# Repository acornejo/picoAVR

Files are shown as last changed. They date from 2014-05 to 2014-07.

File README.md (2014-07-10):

# [PicoAVR](http://acornejo.github.io/picoAVR)

[PicoAVR](http://acornejo.github.io/picoAVR) is an open source AVR
development board which aims to a minimalistic but fully functional
alternative to Arduino.
The PicoAVR board measures less than 1 square inch, and for less than 10$ you can buy all the components to build your own.

Blinky Blinky on PicoAVR

The PicoAVR can be powered and programmed through a standard MicroUSB
connector, the same connector used by android phones and tablets.
PicoAVR uses the [V-USB](http://www.obdev.at/products/vusb/index.html)
software implementation of the USB stack, and when connected to your
computer can easily be programmed to emulate a keyboard,
mouse or any other HID device.

The PicoAVR board is similar in capabilities to the [Arduino
UNO](http://arduino.cc/en/Main/ArduinoBoardUno), [Arduino
Micro](http://arduino.cc/en/Main/arduinoBoardMicro) or the [Arduino
Leonardo](http://arduino.cc/en/Main/arduinoBoardLeonardo), but by using
an atmega328p and V-USB instead of an FTDI chip or an atmega328u4 the
number of components and the cost of the PicoAVR is significantly
reduced.

Since PicoAVR uses the same
[protocol](http://www.obdev.at/products/vusb/usbasploader.html) as the
[usbasp](www.fischl.de/usbasp/) for programming, it is supported by
the latest versions of avrdude. As a result both 
Atmel Studio 6 or the Arduino Software can be used as complete
development environments for the PicoAVR. However, you are not
constrained to these, and you can easily develop for the PicoAVR using
avr-gcc, avrdude and the editor of your choice.

In its default configuration the PicoAVR runs at 12 Mhz and operates at
3.3 V, which makes it easy to interface to the newer 3.3 V devices without
requiring a level shifter.

## PicoAVR may be interesting to you if...

* You are already developing hardware projects using an Arduino, but you
would prefer to build your own hardware.
* You want to get started with AVR microcontrollers, but don't want to
spend 25$ on an Arduino UNO or an Arduino Micro.
* You want an AVR development board which has a standard 6-pin ICSP
connector and can be used as an ICSP programmer for other
microcontrollers.
* You want to create a board of your own using an AVR microcontroller
and you are looking for a simple reference design.

## Build Your Own

You can buy the components to build your own for less than 10$ per board.

Moreover, keep in mind that due to economies of scale, building 100 or
1000 PicoAVR's is significantly cheaper per unit than building a single
board.

The only equipment required to build your own PicoAVR is a soldering
iron and an ICSP programmer to flash the bootloader (more on that below).

### BOM

|Part  | Description | Package | DigiKey Part # | Price ($) |
|---|---|---|---|---|
|C1,C2 | 4.7uF Capacitor | 402 | 1276-1056-1-ND | 0.23 x 2  |
|C3,C4 | 22pF  Capacitor | 402 | 1276-1681-1-ND | 0.1 x 2 |
|C5,C6 | 0.1uF Capacitor | 402 | 1276-1443-1-ND | 0.1 x 2 |
|R1,R2 | 68 Ohm Resistor | 402 | RMCF0402JT68R0CT-ND  | 0.02 x 2  |
|R3 | 1.5k Ohm Resistor | 402 | RMCF0402JT1K50CT-ND  | 0.02 x 1  |
|R4 | 10k Ohm Resistor | 402 | RMCF0402JT10K0CT-ND  | 0.02 x 1  |
|R5 | 220 Ohm Resistor | 402 | RMCF0402JT220RCT-ND  | 0.02 x 1  |
|Q1 | 12 Mhz Crystal | 3.2 x 2.5mm  | 887-2355-1-ND | 0.71 x 1  |
|U1 | Atmega328p | TQFP-32 | ATMEGA328P-AU-ND | 3.61 x 1  |
|IC1 | MCP1700 Voltage Regulator | SOT23 | MCP1700T3302ETTCT-ND | 0.44 x 1  |
|X1 | MicroUSB Connector | USB-MICRO | 609-4613-1-ND | 0.46 x 1  |
|SW1 | Tactile Switch | 3mm x 4mm | CKN10502CT-ND | 0.28 x 1  |

The total comes to less than 6.5$ per board. Digikey offers educational and
bulk discounts.

### PCB

You can get 3 PCB's from [oshpark.com](https://oshpark.com/shared_projects/4zQfKzvO) for only 4.95$
including shipping. That is less than 2$ per PicoAVR board! Click [here](https://oshpark.com/shared_projects/4zQfKzvO) to order your own. 

The eagle board files are available in the
[repository](https://github.com/acornejo/picoAVR/tree/master/hardware).

Below is a rendering of the top and bottom of the PCB.

TopBoard Top View PCB
BottomBoard Bottom View PCB

### Flashing the Bootloader
To get the PicoAVR usbasp-based bootloader flashed into the AVR chip you will
need either: a dedicated [ICSP
programmer](http://store.atmel.com/PartDetail.aspx?q=p:10500054#tc:description),
an [Arduino](http://arduino.cc/en/Tutorial/ArduinoISP) and jumper
cables, or an already functioning PicoAVR.

The PicoAVR provides a standard 6-pin ICSP connector that can be used to
either flash the bootloader into the board (by closing the self-program
jumper), or to act as an ICSP programmer to reprogram any other
AVR board (including another PicoAVR or an Arduino) using a standard
6-pin ICSP connector.

## License

[MIT License](http://opensource.org/licenses/MIT)

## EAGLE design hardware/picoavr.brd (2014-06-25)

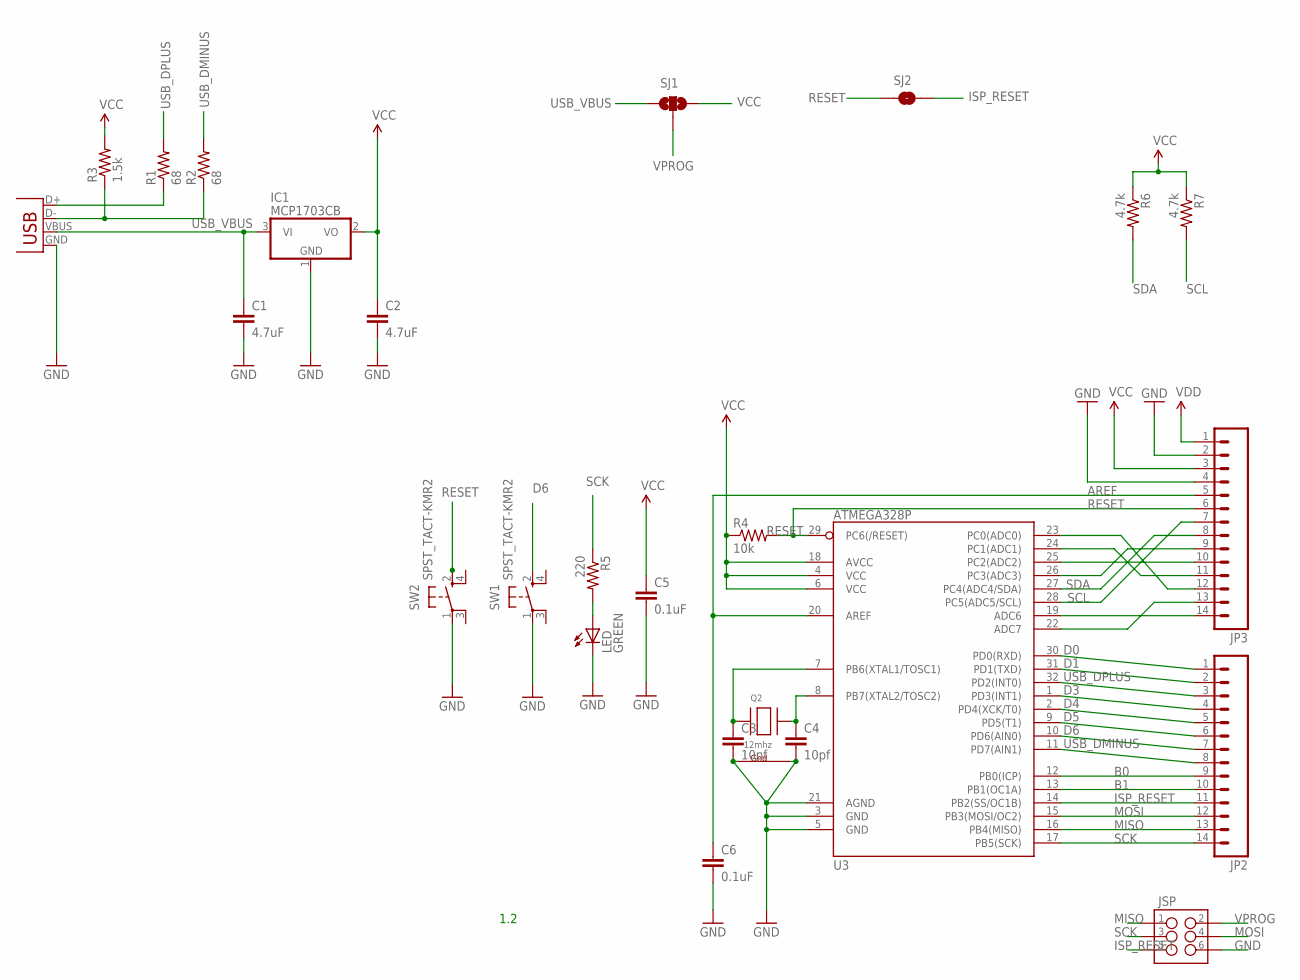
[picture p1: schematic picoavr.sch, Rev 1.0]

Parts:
C1, C2: 4.7uF; 0402-CAP
C3, C4: 10pf; 0402-CAP
C5, C6: 0.1uF; 0402-CAP
IC1: MCP1703CB; SOT23
JP2, JP3: M14LOCK; 1X14_LOCK
JSP: ICSP; 2X3-NS
LED: GREEN; LED-0603
Q2: 12mhz; NX3225
R1, R2: 68; R0402
R3: 1.5k; R0402
R4: 10k; R0402
R5: 220; 0402-RES
R6, R7: 4.7k; 0402-RES
SJ1: SJ1; SJ_3
SJ2: SOLDERJUMPERNO; SJ_2S-NO
SW1, SW2: SPST_TACT-KMR2; KMR2
U3: ATMEGA328P; TQFP32-08
X1: Micro USB; USB-MICROB

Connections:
A0: JP3.12, U3.23 (PC0(ADC0))
A1: JP3.11, U3.24 (PC1(ADC1))
A2: JP3.10, U3.25 (PC2(ADC2))
A3: JP3.9, U3.26 (PC3(ADC3))
A6: JP3.14, U3.19 (ADC6)
A7: JP3.13, U3.22 (ADC7)
AREF: C6.1, JP3.5, U3.20 (AREF)
B0: JP2.9, U3.12 (PB0(ICP))
B1: JP2.10, U3.13 (PB1(OC1A))
D0: JP2.1, U3.30 (PD0(RXD))
D1: JP2.2, U3.31 (PD1(TXD))
D3: JP2.4, U3.1 (PD3(INT1))
D4: JP2.5, U3.2 (PD4(XCK/T0))
D5: JP2.6, U3.9 (PD5(T1))
D6: JP2.7, SW1.2 (S), U3.10 (PD6(AIN0))
GND: C1.2, C2.2, C3.2, C4.2, C5.2, C6.2, IC1.1 (GND), JP3.2, JP3.4, JSP.6, LED.C, Q2.2 (G2), Q2.4 (G1), SW1.1, SW2.1, U3.3 (GND), U3.5 (GND), U3.21 (AGND), X1.GND
ISP_RESET: JP2.11, JSP.5, SJ2.2, U3.14 (PB2(SS/OC1B))
MISO: JP2.13, JSP.1, U3.16 (PB4(MISO))
MOSI: JP2.12, JSP.4, U3.15 (PB3(MOSI/OC2))
unnamed: R1.1, X1.D+
unnamed: R2.1, R3.1, X1.D-
unnamed: C4.1, Q2.3 (X2), U3.8 (PB7(XTAL2/TOSC2))
unnamed: C3.1, Q2.1 (X1), U3.7 (PB6(XTAL1/TOSC1))
unnamed: LED.A, R5.2
RESET: JP3.6, R4.2, SJ2.1, SW2.2 (S), U3.29 (PC6(/RESET))
SCK: JP2.14, JSP.3, R5.1, U3.17 (PB5(SCK))
SCL: JP3.7, R7.2, U3.28 (PC5(ADC5/SCL))
SDA: JP3.8, R6.2, U3.27 (PC4(ADC4/SDA))
USB_DMINUS: JP2.8, R2.2, U3.11 (PD7(AIN1))
USB_DPLUS: JP2.3, R1.2, U3.32 (PD2(INT0))
USB_VBUS: C1.1, IC1.3 (VI), JP3.1, SJ1.1, X1.VBUS
VCC: C2.1, C5.1, IC1.2 (VO), JP3.3, R3.2, R4.1, R6.1, R7.1, SJ1.3, U3.4 (VCC), U3.6 (VCC), U3.18 (AVCC)
VPROG: JSP.2, SJ1.2

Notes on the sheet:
1.2

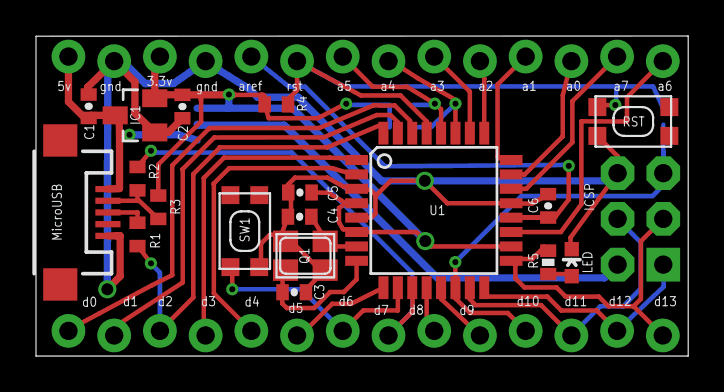
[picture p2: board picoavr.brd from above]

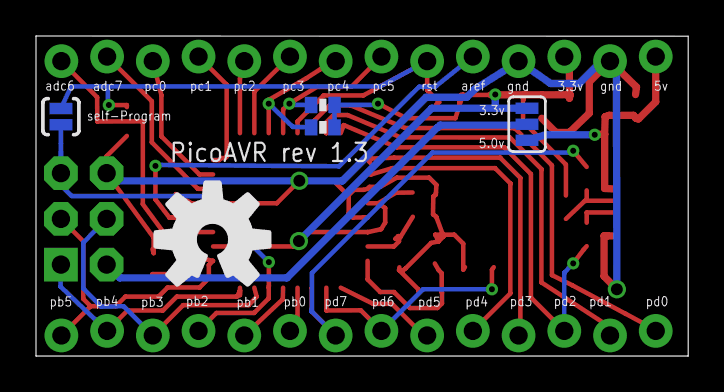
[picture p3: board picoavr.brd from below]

Board: 2 copper layers, 36.2 x 17.8 mm, 25 parts (4 on the bottom side), 33 nets.

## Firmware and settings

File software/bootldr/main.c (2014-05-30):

/* Name: main.c
 * Project: USBaspLoader
 * Author: Christian Starkjohann
 * Author: Stephan Baerwolf
 * Creation Date: 2007-12-08
 * Modification Date: 2013-03-31
 * Tabsize: 4
 * Copyright: (c) 2007 by OBJECTIVE DEVELOPMENT Software GmbH
 * License: GNU GPL v2 (see License.txt)
 */

#include "spminterface.h"  /* must be included as first! */

#include <avr/io.h>
#include <avr/interrupt.h>
#include <avr/pgmspace.h>
#include <avr/wdt.h>
#include <avr/boot.h>
#include <avr/eeprom.h>
#include <util/delay.h>
#include <avr/boot.h>

#include <string.h>

#ifndef SPMEN
#define SPMEN SELFPRGEN
#endif



#include "bootloaderconfig.h"
#include "../usbdrv/usbdrv.h"

#ifndef BOOTLOADER_ADDRESS
  #error need to know the bootloaders flash address!
#endif
#define BOOTLOADER_PAGEADDR	(BOOTLOADER_ADDRESS - (BOOTLOADER_ADDRESS % SPM_PAGESIZE))

/* ------------------------------------------------------------------------ */

/* Request constants used by USBasp */
#define USBASP_FUNC_CONNECT         1
#define USBASP_FUNC_DISCONNECT      2
#define USBASP_FUNC_TRANSMIT        3
#define USBASP_FUNC_READFLASH       4
#define USBASP_FUNC_ENABLEPROG      5
#define USBASP_FUNC_WRITEFLASH      6
#define USBASP_FUNC_READEEPROM      7
#define USBASP_FUNC_WRITEEEPROM     8
#define USBASP_FUNC_SETLONGADDRESS  9

// additional USBasp Commands
#define USBASP_FUNC_SETISPSCK	     10
#define USBASP_FUNC_TPI_CONNECT      11
#define USBASP_FUNC_TPI_DISCONNECT   12
#define USBASP_FUNC_TPI_RAWREAD      13
#define USBASP_FUNC_TPI_RAWWRITE     14
#define USBASP_FUNC_TPI_READBLOCK    15
#define USBASP_FUNC_TPI_WRITEBLOCK   16
#define USBASP_FUNC_GETCAPABILITIES 127
/* ------------------------------------------------------------------------ */

#ifndef ulong
#   define ulong    unsigned long
#endif
#ifndef uint
#   define uint     unsigned int
#endif

/* device compatibility: */
#ifndef GICR    /* ATMega*8 don't have GICR, use MCUCR instead */
#   define GICR     MCUCR
#endif

/* ------------------------------------------------------------------------ */

#if (FLASHEND) > 0xffff /* we need long addressing */
#   define CURRENT_ADDRESS  currentAddress.l
#   define addr_t           ulong
#else
#   define CURRENT_ADDRESS  currentAddress.w[0]
#   define addr_t           uint
#endif

typedef union longConverter{
    addr_t  l;
    uint    w[sizeof(addr_t)/2];
    uchar   b[sizeof(addr_t)];
}longConverter_t;


#if (BOOTLOADER_CAN_EXIT)
#	if (BOOTLOADER_LOOPCYCLES_TIMEOUT)
#		if (BOOTLOADER_LOOPCYCLES_TIMEOUT < 256)
#			if ((HAVE_UNPRECISEWAIT))
volatile register uint8_t timeout_remaining __asm__("r2");
#			else
static volatile uint8_t timeout_remaining;
#			endif
#		else
static volatile uint16_t timeout_remaining;
#		endif
#	endif

#	define stayinloader_initialValue 0xfe
#	if ((HAVE_UNPRECISEWAIT))
/* here we have to assume we need to optimize for every byte */
volatile register uint8_t stayinloader __asm__("r17");
#	else
static volatile uint8_t stayinloader;
#	endif
#endif

static longConverter_t  	currentAddress; /* in bytes */
static uchar            	bytesRemaining;
static uchar            	isLastPage;
#if HAVE_EEPROM_PAGED_ACCESS
static uchar            	currentRequest;
#else
static const uchar      	currentRequest = 0;
#endif

static const uchar  signatureBytes[4] = {
#ifdef SIGNATURE_BYTES
    SIGNATURE_BYTES
#elif defined (__AVR_ATmega8535__)
    0x1e, 0x93, 0x08, 0
#elif defined (__AVR_ATmega8__) || defined (__AVR_ATmega8A__) || defined (__AVR_ATmega8HVA__)
    0x1e, 0x93, 0x07, 0
#elif defined (__AVR_ATmega16__)
    0x1e, 0x94, 0x03, 0
#elif defined (__AVR_ATmega32__)
    0x1e, 0x95, 0x02, 0
#elif defined (__AVR_ATmega48__) || defined (__AVR_ATmega48A__) || defined (__AVR_ATmega48P__)
    #error ATmega48 does not support bootloaders!
    0x1e, 0x92, 0x05, 0
#elif defined (__AVR_ATmega48PA__)
    #error ATmega48 does not support bootloaders!
    0x1e, 0x92, 0x0A, 0
#elif defined (__AVR_ATmega88__) || defined (__AVR_ATmega88A__) || defined (__AVR_ATmega88P__)
    0x1e, 0x93, 0x0a, 0
#elif defined (__AVR_ATmega88PA__)
    0x1e, 0x93, 0x0F, 0
#elif defined (__AVR_ATmega162__)
    0x1e, 0x94, 0x04, 0
#elif defined (__AVR_ATmega164A__)
    0x1e, 0x94, 0x0f, 0
#elif defined (__AVR_ATmega164P__) || defined (__AVR_ATmega164PA__)
    0x1e, 0x94, 0x0a, 0
#elif defined (__AVR_ATmega168__) || defined (__AVR_ATmega168A__) || defined (__AVR_ATmega168P__)
    0x1e, 0x94, 0x06, 0
#elif defined (__AVR_ATmega168PA__)
    0x1e, 0x94, 0x0B, 0
#elif defined (__AVR_ATmega324A__)
    0x1e, 0x95, 0x15, 0
#elif defined (__AVR_ATmega324P__)
    0x1e, 0x95, 0x08, 0
#elif defined (__AVR_ATmega324PA__)
    0x1e, 0x95, 0x11, 0
#elif defined (__AVR_ATmega328__)
    0x1e, 0x95, 0x14, 0
#elif defined (__AVR_ATmega328P__)
    0x1e, 0x95, 0x0f, 0
#elif defined (__AVR_ATmega640__)
    0x1e, 0x96, 0x08, 0
#elif defined (__AVR_ATmega644__) || defined (__AVR_ATmega644A__)
    0x1e, 0x96, 0x09, 0
#elif defined (__AVR_ATmega644P__) || defined (__AVR_ATmega644PA__)
    0x1e, 0x96, 0x0a, 0
#elif defined (__AVR_ATmega128__)
    0x1e, 0x97, 0x02, 0
#elif defined (__AVR_ATmega1280__)
    0x1e, 0x97, 0x03, 0
#elif defined (__AVR_ATmega1281__)
    0x1e, 0x97, 0x04, 0
#elif defined (__AVR_ATmega1284__)
    0x1e, 0x97, 0x06, 0
#elif defined (__AVR_ATmega1284P__)
    0x1e, 0x97, 0x05, 0
#elif defined (__AVR_ATmega2560__)
    0x1e, 0x98, 0x01, 0
#elif defined (__AVR_ATmega2561__)
    0x1e, 0x98, 0x02, 0
#else
#   if (defined(SIGNATURE_0) && defined(SIGNATURE_1) && defined(SIGNATURE_2))
#     warning "Device signature is not known - using AVR Libc suggestion..."
    SIGNATURE_0, SIGNATURE_1, SIGNATURE_2, 0
#   else
#     error "Device signature is not known, please edit main.c!"
#   endif
#endif
};

/* ------------------------------------------------------------------------ */

#if (HAVE_BOOTLOADERENTRY_FROMSOFTWARE)
void __attribute__ ((section(".init3"),naked,used,no_instrument_function)) __BOOTLOADERENTRY_FROMSOFTWARE__bootup_investigate_RAMEND(void);
void __BOOTLOADERENTRY_FROMSOFTWARE__bootup_investigate_RAMEND(void) {
  asm volatile (
    "in		%[mcucsrval]	,	%[mcucsrio]\n\t"
    "ldi	r29		,	%[ramendhi]\n\t"
    "ldi	r28		,	%[ramendlo]\n\t"
#if (FLASHEND>131071)
    "ld		%[result]	,	Y+\n\t"
    "cpi	%[result]	,	%[bootaddrhi]\n\t"
    "brne	__BOOTLOADERENTRY_FROMSOFTWARE__bootup_investigate_RAMEND_mismatch%=\n\t"
#endif
    "ld		%[result]	,	Y+\n\t"
    "cpi	%[result]	,	%[bootaddrme]\n\t"
    "ld		%[result]	,	Y+\n\t"
    "breq	__BOOTLOADERENTRY_FROMSOFTWARE__bootup_investigate_RAMEND_done%=\n\t"

    "__BOOTLOADERENTRY_FROMSOFTWARE__bootup_investigate_RAMEND_mismatch%=:\n\t"
    "ldi	%[result]	,	0xff\n\t"

    "__BOOTLOADERENTRY_FROMSOFTWARE__bootup_investigate_RAMEND_done%=:\n\t"
    : [result]		"=a" (__BOOTLOADERENTRY_FROMSOFTWARE__bootup_RAMEND_doesmatch),
      [mcucsrval]	"=a" (__BOOTLOADERENTRY_FROMSOFTWARE__bootup_MCUCSR)
    : [mcucsrio]	"I"  (_SFR_IO_ADDR(MCUCSR)),
#if (FLASHEND>131071)
      [ramendhi]	"M" (((RAMEND - 2) >> 8) & 0xff),
      [ramendlo]	"M" (((RAMEND - 2) >> 0) & 0xff),
      [bootaddrhi]	"M" (((__BOOTLOADERENTRY_FROMSOFTWARE__EXPECTEDADDRESS) >>16) & 0xff),
#else
      [ramendhi]	"M" (((RAMEND - 1) >> 8) & 0xff),
      [ramendlo]	"M" (((RAMEND - 1) >> 0) & 0xff),
#endif
      [bootaddrme]	"M" (((__BOOTLOADERENTRY_FROMSOFTWARE__EXPECTEDADDRESS) >> 8) & 0xff)
    
  );
}
#endif

#if (USE_BOOTUP_CLEARRAM)
/*
* Under normal circumstances, RESET will not clear contents of RAM.
* As always, if you want it done - do it yourself...
*/
void __attribute__ ((section(".init3"),naked,used,no_instrument_function)) __func_clearram(void);
void __func_clearram(void) {
  extern size_t __bss_end;
  asm volatile (
    "__clearram:\n\t"
#if (!(HAVE_BOOTLOADERENTRY_FROMSOFTWARE))
    "ldi r29, %[ramendhi]\n\t"
    "ldi r28, %[ramendlo]\n\t"
#endif
    "__clearramloop%=:\n\t"
    "st -Y , __zero_reg__\n\t"
    "cp r28, %A[bssend]\n\t"
    "cpc r29, %B[bssend]\n\t"
    "brne __clearramloop%=\n\t"
    :
    : [ramendhi] "M" (((RAMEND+1)>>8) & 0xff),
      [ramendlo] "M" (((RAMEND+1)>>0) & 0xff),
      [bssend] "r" (&__bss_end)
    : "memory"
      );
}
#endif

#if (!USE_EXCESSIVE_ASSEMBLER) || (!(defined (__AVR_ATmega8__) || defined (__AVR_ATmega8A__) || defined (__AVR_ATmega8HVA__)))
static void (*nullVector)(void) __attribute__((__noreturn__)) = 0x0000;
#endif

#if (USE_EXCESSIVE_ASSEMBLER) && (defined (__AVR_ATmega8__) || defined (__AVR_ATmega8A__) || defined (__AVR_ATmega8HVA__))
static void __attribute__((naked,__noreturn__)) leaveBootloader(void);
static void leaveBootloader(void) {
  asm  volatile  (
  "cli\n\t"
  "sbi		%[usbddr],	%[usbminus]\n\t"  
  "cbi		%[port],	%[bit]\n\t"
  "out		%[usbintrenab],	__zero_reg__\n\t"
  "out		%[usbintrcfg],	__zero_reg__\n\t"
  "ldi		r31,		%[ivce]\n\t"
  "out		%[mygicr],	r31\n\t"
  "out		%[mygicr],	__zero_reg__\n\t"  
  "rjmp		nullVector\n\t"
  :
  : [port]        "I" (_SFR_IO_ADDR(PIN_PORT(JUMPER_PORT))),
    [bit]         "I" (PIN(JUMPER_PORT, JUMPER_BIT)),
    [usbintrenab] "I" (_SFR_IO_ADDR(USB_INTR_ENABLE)),
    [usbintrcfg]  "I" (_SFR_IO_ADDR(USB_INTR_CFG)),
    [usbddr]      "I" (_SFR_IO_ADDR(USBDDR)),
    [usbminus]    "I" (USBMINUS),
    [mygicr]      "I" (_SFR_IO_ADDR(GICR)),	      
    [ivce]        "I" (1<<IVCE)
);
}
#else
static void __attribute__((__noreturn__)) leaveBootloader(void);
static void leaveBootloader(void) {
    cli();
    usbDeviceDisconnect();
    bootLoaderExit();
    USB_INTR_ENABLE = 0;
    USB_INTR_CFG = 0;       /* also reset config bits */
    GICR = (1 << IVCE);     /* enable change of interrupt vectors */
    GICR = (0 << IVSEL);    /* move interrupts to application flash section */

/*
 * There seems to be another funny compiler Bug.
 * When gcc is using "eicall" opcode it forgets to modify EIND.
 * On devices with large flash memory there are some target address bits
 * missing. In this case some zero bits...
 */
#if (defined(EIND) && ((FLASHEND)>131071))
  EIND=0;
#endif
/* We must go through a global function pointer variable instead of writing
 *  ((void (*)(void))0)();
 * because the compiler optimizes a constant 0 to "rcall 0" which is not
 * handled correctly by the assembler.
 */
    nullVector();
}
#endif

/* ------------------------------------------------------------------------ */


uchar usbFunctionSetup_USBASP_FUNC_TRANSMIT(usbRequest_t *rq) {
  uchar rval = 0;
  usbWord_t address;
  address.bytes[1] = rq->wValue.bytes[1];
  address.bytes[0] = rq->wIndex.bytes[0];

  if(rq->wValue.bytes[0] == 0x30){        /* read signature */
    rval = rq->wIndex.bytes[0] & 3;
    rval = signatureBytes[rval];
#if HAVE_READ_LOCK_FUSE
#if defined (__AVR_ATmega8535__) || 					\
    defined (__AVR_ATmega8__) || defined (__AVR_ATmega8A__) || 		\
    defined (__AVR_ATmega16__) || defined (__AVR_ATmega32__)
  }else if(rq->wValue.bytes[0] == 0x58 && rq->wValue.bytes[1] == 0x00){  /* read lock bits */
      rval = boot_lock_fuse_bits_get(GET_LOCK_BITS);
  }else if(rq->wValue.bytes[0] == 0x50 && rq->wValue.bytes[1] == 0x00){  /* read lfuse bits */
      rval = boot_lock_fuse_bits_get(GET_LOW_FUSE_BITS);
  }else if(rq->wValue.bytes[0] == 0x58 && rq->wValue.bytes[1] == 0x08){  /* read hfuse bits */
      rval = boot_lock_fuse_bits_get(GET_HIGH_FUSE_BITS);

#elif defined (__AVR_ATmega48__)   || defined (__AVR_ATmega48A__)   || defined (__AVR_ATmega48P__)   || defined (__AVR_ATmega48PA__)  ||  \
defined (__AVR_ATmega88__)   || defined (__AVR_ATmega88A__)   || defined (__AVR_ATmega88P__)   || defined (__AVR_ATmega88PA__)  ||  \
defined (__AVR_ATmega162__)  || 												      \
defined (__AVR_ATmega164A__) || defined (__AVR_ATmega164P__)  || 								      \
defined (__AVR_ATmega168__)  || defined (__AVR_ATmega168A__)  || defined (__AVR_ATmega168P__)  || defined (__AVR_ATmega168PA__) ||  \
defined (__AVR_ATmega324A__) || defined (__AVR_ATmega324P__)  ||								      \
defined (__AVR_ATmega328__)  || defined (__AVR_ATmega328P__)  ||								      \
defined (__AVR_ATmega640__)  ||													\
defined (__AVR_ATmega644__)  || defined (__AVR_ATmega644A__)  || defined (__AVR_ATmega644P__) || defined (__AVR_ATmega644PA__)  ||  \
defined (__AVR_ATmega128__)  ||													      \
defined (__AVR_ATmega1280__) ||													\
defined (__AVR_ATmega1281__) ||													\
defined (__AVR_ATmega1284__) || defined (__AVR_ATmega1284P__)  ||													\
defined (__AVR_ATmega2560__) ||													\
defined (__AVR_ATmega2561__)
  }else if(rq->wValue.bytes[0] == 0x58 && rq->wValue.bytes[1] == 0x00){  /* read lock bits */
      rval = boot_lock_fuse_bits_get(GET_LOCK_BITS);
  }else if(rq->wValue.bytes[0] == 0x50 && rq->wValue.bytes[1] == 0x00){  /* read lfuse bits */
      rval = boot_lock_fuse_bits_get(GET_LOW_FUSE_BITS);
  }else if(rq->wValue.bytes[0] == 0x58 && rq->wValue.bytes[1] == 0x08){  /* read hfuse bits */
      rval = boot_lock_fuse_bits_get(GET_HIGH_FUSE_BITS);
  }else if(rq->wValue.bytes[0] == 0x50 && rq->wValue.bytes[1] == 0x08){  /* read efuse bits */
      rval = boot_lock_fuse_bits_get(GET_EXTENDED_FUSE_BITS );
#else
  #warning "HAVE_READ_LOCK_FUSE is activated but MCU unknown -> will not support this feature"
#endif
#endif
#if HAVE_FLASH_BYTE_READACCESS
  }else if(rq->wValue.bytes[0] == 0x20){  /* read FLASH low  byte */
#if ((FLASHEND) > 65535)
      rval = pgm_read_byte_far((((addr_t)address.word)<<1)+0);
#else
      rval = pgm_read_byte((((addr_t)address.word)<<1)+0);
#endif
  }else if(rq->wValue.bytes[0] == 0x28){  /* read FLASH high byte */
#if ((FLASHEND) > 65535)
      rval = pgm_read_byte_far((((addr_t)address.word)<<1)+1);
#else
      rval = pgm_read_byte((((addr_t)address.word)<<1)+1);
#endif
#endif
#if HAVE_EEPROM_BYTE_ACCESS
  }else if(rq->wValue.bytes[0] == 0xa0){  /* read EEPROM byte */
      rval = eeprom_read_byte((void *)address.word);
  }else if(rq->wValue.bytes[0] == 0xc0){  /* write EEPROM byte */
      eeprom_write_byte((void *)address.word, rq->wIndex.bytes[1]);
#endif
#if HAVE_CHIP_ERASE
  }else if(rq->wValue.bytes[0] == 0xac && rq->wValue.bytes[1] == 0x80){  /* chip erase */
      addr_t addr;
#if HAVE_BLB11_SOFTW_LOCKBIT
      for(addr = 0; addr < (addr_t)(BOOTLOADER_PAGEADDR) ; addr += SPM_PAGESIZE) {
#else
      for(addr = 0; addr <= (addr_t)(FLASHEND) ; addr += SPM_PAGESIZE) {
#endif
#   ifndef NO_FLASH_WRITE
	  boot_spm_busy_wait();
	  cli();
	  boot_page_erase(addr);
	  sei();
#   endif
      }
#endif
#if ((HAVE_BOOTLOADER_HIDDENEXITCOMMAND) && (BOOTLOADER_CAN_EXIT))
#	if ((HAVE_BOOTLOADER_HIDDENEXITCOMMAND != 0xac) && \
	    (HAVE_BOOTLOADER_HIDDENEXITCOMMAND != 0x20) && (HAVE_BOOTLOADER_HIDDENEXITCOMMAND != 0x28) && \
	    (HAVE_BOOTLOADER_HIDDENEXITCOMMAND != 0x40) && (HAVE_BOOTLOADER_HIDDENEXITCOMMAND != 0x48) && \
	    (HAVE_BOOTLOADER_HIDDENEXITCOMMAND != 0x4c) && \
	    (HAVE_BOOTLOADER_HIDDENEXITCOMMAND != 0xa0) && \
	    (HAVE_BOOTLOADER_HIDDENEXITCOMMAND != 0xc0) && \
	    (HAVE_BOOTLOADER_HIDDENEXITCOMMAND != 0x58) && \
	    (HAVE_BOOTLOADER_HIDDENEXITCOMMAND != 0x5c) && \
	    (HAVE_BOOTLOADER_HIDDENEXITCOMMAND != 0x30) && \
	    (HAVE_BOOTLOADER_HIDDENEXITCOMMAND != 0xac) && \
	    (HAVE_BOOTLOADER_HIDDENEXITCOMMAND != 0x50) && (HAVE_BOOTLOADER_HIDDENEXITCOMMAND != 0x58) && \
	    (HAVE_BOOTLOADER_HIDDENEXITCOMMAND != 0x38))
  }else if(rq->wValue.bytes[0] == (HAVE_BOOTLOADER_HIDDENEXITCOMMAND)){  /* cause a bootLoaderExit at disconnect */
      stayinloader = 0xf1;  /* we need to be connected - so assume it */
#	endif
#endif
  }else{
      /* ignore all others, return default value == 0 */
  }
        
  return rval;
}


usbMsgLen_t usbFunctionSetup(uchar data[8])
{
usbRequest_t    *rq = (void *)data;
usbMsgLen_t     len = 0;
static uchar    replyBuffer[4];

    usbMsgPtr = (usbMsgPtr_t)replyBuffer;
    if(rq->bRequest == USBASP_FUNC_TRANSMIT){   /* emulate parts of ISP protocol */
        replyBuffer[3] = usbFunctionSetup_USBASP_FUNC_TRANSMIT(rq);
        len = (usbMsgLen_t)4;
    }else if((rq->bRequest == USBASP_FUNC_ENABLEPROG) || (rq->bRequest == USBASP_FUNC_SETISPSCK)){
        /* replyBuffer[0] = 0; is never touched and thus always 0 which means success */
        len = (usbMsgLen_t)1;
    }else if(rq->bRequest >= USBASP_FUNC_READFLASH && rq->bRequest <= USBASP_FUNC_SETLONGADDRESS){
        currentAddress.w[0] = rq->wValue.word;
        if(rq->bRequest == USBASP_FUNC_SETLONGADDRESS){
#if (FLASHEND) > 0xffff
            currentAddress.w[1] = rq->wIndex.word;
#endif
        }else{
            bytesRemaining = rq->wLength.bytes[0];
            /* if(rq->bRequest == USBASP_FUNC_WRITEFLASH) only evaluated during writeFlash anyway */
            isLastPage = rq->wIndex.bytes[1] & 0x02;
#if HAVE_EEPROM_PAGED_ACCESS
            currentRequest = rq->bRequest;
#endif
            len = USB_NO_MSG; /* hand over to usbFunctionRead() / usbFunctionWrite() */
        }

    }else if(rq->bRequest == USBASP_FUNC_DISCONNECT){

#if BOOTLOADER_CAN_EXIT
#	ifdef CONFIG_HAVE__BOOTLOADER_ABORTTIMEOUTONACT
      /* let the main loop know for ever that here was activity */
      stayinloader	   &= (0xfc);
#	else
      stayinloader	   &= (0xfe);
#	endif
#endif
    }else{
        /* ignore: others, but could be USBASP_FUNC_CONNECT */
#if BOOTLOADER_CAN_EXIT
	stayinloader	   |= (0x01);
#endif
    }
    return len;
}

#if (USE_EXCESSIVE_ASSEMBLER) && ((!HAVE_CHIP_ERASE) || (HAVE_ONDEMAND_PAGEERASE)) && (SPM_PAGESIZE <= 256) && (((BOOTLOADER_PAGEADDR>>0)&0xff) == 0)
uchar usbFunctionWrite(uchar *data, uchar len)
{
uchar   isLast;

    if(len > bytesRemaining)
        len = bytesRemaining;
    bytesRemaining -= len;
    isLast = bytesRemaining == 0;
    if(currentRequest >= USBASP_FUNC_READEEPROM){
        uchar i;
        for(i = 0; i < len; i++){
            eeprom_write_byte((void *)(currentAddress.w[0]++), *data++);
        }
    }else{
	asm  volatile  (
	  "sbrc		%[len], 0\n\t"
	  "inc		%[len]\n\t"
"usbFunctionWrite_flashloop:\n\t"
	  "subi		%[len], 2\n\t"
	  "brlo		usbFunctionWrite_finished\n\t"
	  
#if HAVE_BLB11_SOFTW_LOCKBIT
	  "cpi		r31, %[blsaddrhi]\n\t"			/* accelerated BLB11_SOFTW_LOCKBIT check */
	  "brsh		usbFunctionWrite_finished\n\t"
// 	  "brlo		usbFunctionWrite_addrunlock_ok\n\t"
// 	  "brne		usbFunctionWrite_finished\n\t"
// 	  "cpi		r30, %[blsaddrlo]\n\t"
// 	  "brlo		usbFunctionWrite_addrunlock_ok\n\t"
// 	  "rjmp		usbFunctionWrite_finished\n\t"
// "usbFunctionWrite_addrunlock_ok:\n\t"
#endif
	  "rcall	usbFunctionWrite_waitA\n\t"
	  "cli\n\t"						/* r0 or r1 may be __zero_reg__ and may become dangerous nonzero within interrupts */
	  "ld		r0,		X+\n\t"
	  "ld		r1,		X+\n\t"

	  "ldi		r18,		%[pagfillval]\n\t"
	  "rcall	usbFunctionWrite_saveflash\n\t"	/* page fill */

	  "mov		r18,		r30\n\t"
	  "subi		r18,		0xfe\n\t"		/* add with 2 */
	  "andi		r18,		%[pagemask]\n\t"
	  "breq		usbFunctionWrite_pageisfull\n\t"
	  "tst		%[islast]\n\t"
	  "breq		usbFunctionWrite_skippageisfull\n\t"
	  "tst		%[isLastPage]\n\t"
	  "breq		usbFunctionWrite_skippageisfull\n\t"
	  "cpi		%[len],		0\n\t"
	  "brne		usbFunctionWrite_skippageisfull\n\t"

"usbFunctionWrite_pageisfull:\n\t"				/* start writing the page */
	  "ldi		r18,		%[pageraseval]\n\t"
	  "rcall	usbFunctionWrite_saveflash\n\t"	/* page erase */
	  "rcall	usbFunctionWrite_waitA\n\t"

	  "ldi		r18,		%[pagwriteval]\n\t"
	  "rcall	usbFunctionWrite_saveflash\n\t"	/* page write */
	  "rcall	usbFunctionWrite_waitA\n\t"

	  "in		__tmp_reg__,	%[spmcr]\n\t"
	  "sbrs		__tmp_reg__,	%[rwwsbbit]\n\t"
	  "rjmp		usbFunctionWrite_skippageisfull\n\t"
	  "ldi		r18,		%[rwwenrval]\n\t"
	  "rcall	usbFunctionWrite_saveflash\n\t"	/* reenable rww*/
// 	  "rcall	usbFunctionWrite_waitA\n\t"


"usbFunctionWrite_skippageisfull:\n\t"	  
	  "adiw		r30,		0x2\n\t"
	  "rjmp		usbFunctionWrite_flashloop\n\t"

"usbFunctionWrite_saveflash:\n\t"
	  "cli\n\t"
	  "out		%[spmcr],	r18\n\t"
	  "spm\n\t"
	  "clr		__zero_reg__\n\t"			/* if r0 or r1 is __zero_reg__ it may have become inconsisten while page-fill */
	  "sei\n\t"
	  "ret\n\t"

"usbFunctionWrite_waitA:\n\t"
	  "in		__tmp_reg__,	%[spmcr]\n\t"
	  "sbrc		__tmp_reg__,	%[spmenbit]\n\t"
	  "rjmp		usbFunctionWrite_waitA\n\t"
	  "ret\n\t"

"usbFunctionWrite_finished:\n\t"
	  : [addr]	   "+z" (currentAddress.l)

	  : [spmenbit]    "I" (SPMEN),
	    [rwwsbbit]    "I" (RWWSB),
	    [spmcr]       "I" (_SFR_IO_ADDR(__SPM_REG)),
	    [pagfillval]  "M" ((1<<SPMEN)),
	    [pageraseval] "M" ((1<<PGERS) | (1<<SPMEN)),
	    [pagwriteval] "M" ((1<<PGWRT) | (1<<SPMEN)),
	    [rwwenrval]   "M" ((1<<RWWSRE) | (1<<SPMEN)),
	    [pagemask]    "M" (SPM_PAGESIZE-1),
#if HAVE_BLB11_SOFTW_LOCKBIT
	    [blsaddrhi]	   "M" ((uint8_t)((BOOTLOADER_PAGEADDR>>8)&0xff)),
// 	    [blsaddrlo]	   "M" ((uint8_t)((BOOTLOADER_PAGEADDR>>0)&0xff)),
#endif
	    [islast]      "r"  (isLast),
	    [isLastPage]  "r"  (isLastPage),
	    [len]	   "d" (len),
	    [dataptr]	   "x" (data)

	    : "r0", "r1", "r18"
	);
    }
    return isLast;
}
#else
uchar usbFunctionWrite(uchar *data, uchar len)
{
uchar   i,isLast;

    if(len > bytesRemaining)
        len = bytesRemaining;
    bytesRemaining -= len;
    isLast = bytesRemaining == 0;
    for(i = 0; i < len;) {
      if(currentRequest >= USBASP_FUNC_READEEPROM){
	eeprom_write_byte((void *)(currentAddress.w[0]++), *data++);
	i++;
      } else {
#if HAVE_BLB11_SOFTW_LOCKBIT
	if (CURRENT_ADDRESS >= (addr_t)(BOOTLOADER_PAGEADDR)) {
	  return 1;
	}
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

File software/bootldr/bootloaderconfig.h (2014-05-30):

/* Name: bootloaderconfig.h
 * Project: USBaspLoader
 * Author: Christian Starkjohann
 * Author: Stephan Baerwolf
 * Creation Date: 2007-12-08
 * Modification Date: 2013-03-31
 * Tabsize: 4
 * Copyright: (c) 2007 by OBJECTIVE DEVELOPMENT Software GmbH
 * License: GNU GPL v2 (see License.txt)
 */

#ifndef __bootloaderconfig_h_included__
#define __bootloaderconfig_h_included__

#include <avr/io.h>

#define JUMPER_INPUT_PORT PIND
#define JUMPER_OUTPUT_PORT PORTD
#define JUMPER_PIN PD6

/*
General Description:
This file (together with some settings in Makefile) configures the boot loader
according to the hardware.

This file contains two functions or macros: bootLoaderInit() and
bootLoaderCondition(). Whether you implement them as macros or as static
inline functions is up to you, decide based on code size and convenience.

bootLoaderInit() is called as one of the first actions after reset. It should
be a minimum initialization of the hardware so that the boot loader condition
can be read. This will usually consist of activating a pull-up resistor for an
external jumper which selects boot loader mode.

bootLoaderCondition() is called immediately after initialization and in each
main loop iteration. If it returns TRUE, the boot loader will be active. If it
returns FALSE, the boot loader jumps to address 0 (the loaded application)
immediately.
*/

/* ------------------------------------------------------------------------- */
/* ---------------------- feature / code size options ---------------------- */
/* ------------------------------------------------------------------------- */

#ifndef CONFIG_NO__HAVE_READ_LOCK_FUSE
  #define HAVE_READ_LOCK_FUSE	    1
#else
  #define HAVE_READ_LOCK_FUSE	    0
#endif
/*
 * enable the loaders capability to load its lfuse, hfuse and lockbits
 * ...However, programming of these is prohibited...
 */

#ifndef CONFIG_NO__HAVE_BLB11_SOFTW_LOCKBIT
  #define HAVE_BLB11_SOFTW_LOCKBIT    1
#else
  #define HAVE_BLB11_SOFTW_LOCKBIT    0
#endif
/*
 * The IC itself do not need to prgra BLB11, but the bootloader will avaoid 
 * to erase itself from the bootregion
 */

#ifndef CONFIG_NO__HAVE_SPMINTEREFACE
  #define HAVE_SPMINTEREFACE	    1
#else
  #define HAVE_SPMINTEREFACE	    0
#endif
/*
 * Since code within normal section of application memory (rww-section) is
 * not able to call spm for programming flash-pages, this option (when
 * enabled) will insert a small subroutine into the bootloader-section
 * to enable applications to circumvent this limitation and make them
 * able to program the flash in a similar way as the bootloader does, too.
 * For further details see "spminterface.h", which implements this 
 * feature.
 */

#define HAVE_SPMINTEREFACE_NORETMAGIC	0
/*
 * If sth. went wrong within "bootloader__do_spm" and this macro is ACTIVATED,
 * then "bootloader__do_spm" will not return the call and loop infinity instead.
 * 
 * This feature prevents old updaters to do sth. undefined on wrong magic.
 */
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

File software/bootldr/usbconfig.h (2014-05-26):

/* Name: usbconfig.h
 * Project: V-USB, virtual USB port for Atmel's(r) AVR(r) microcontrollers
 * Author: Christian Starkjohann
 * Creation Date: 2005-04-01
 * Tabsize: 4
 * Copyright: (c) 2005 by OBJECTIVE DEVELOPMENT Software GmbH
 * License: GNU GPL v2 (see License.txt), GNU GPL v3 or proprietary (CommercialLicense.txt)
 */

#ifndef __usbconfig_h_included__
#define __usbconfig_h_included__

/*
General Description:
This file contains parts of the USB driver which can be configured and can or
must be adapted to your hardware.

Please note that the usbdrv contains a usbconfig-prototype.h file now. We
recommend that you use that file as a template because it will always list
the newest features and options.
*/

/* ---------------------------- Hardware Config ---------------------------- */

#define USB_CFG_IOPORTNAME      D
/* This is the port where the USB bus is connected. When you configure it to
 * "B", the registers PORTB, PINB and DDRB will be used.
 */
#define USB_CFG_DMINUS_BIT      7
/* This is the bit number in USB_CFG_IOPORT where the USB D- line is connected.
 * This may be any bit in the port.
 */
#define USB_CFG_DPLUS_BIT       2
/* This is the bit number in USB_CFG_IOPORT where the USB D+ line is connected.
 * This may be any bit in the port. Please note that D+ must also be connected
 * to interrupt pin INT0!
 */
#define USB_CFG_CLOCK_KHZ (F_CPU/1000)
/* Clock rate of the AVR in MHz. Legal values are 12000, 16000 or 16500.
 * The 16.5 MHz version of the code requires no crystal, it tolerates +/- 1%
 * deviation from the nominal frequency. All other rates require a precision
 * of 2000 ppm and thus a crystal!
 * Default if not specified: 12 MHz
 */

/* ----------------------- Optional Hardware Config ------------------------ */

/* #define USB_CFG_PULLUP_IOPORTNAME   D */
/* If you connect the 1.5k pullup resistor from D- to a port pin instead of
 * V+, you can connect and disconnect the device from firmware by calling
 * the macros usbDeviceConnect() and usbDeviceDisconnect() (see usbdrv.h).
 * This constant defines the port on which the pullup resistor is connected.
 */
/* #define USB_CFG_PULLUP_BIT          4 */
/* This constant defines the bit number in USB_CFG_PULLUP_IOPORT (defined
 * above) where the 1.5k pullup resistor is connected. See description
 * above for details.
 */

/* --------------------------- Functional Range ---------------------------- */

#define USB_CFG_HAVE_INTRIN_ENDPOINT    0
/* Define this to 1 if you want to compile a version with two endpoints: The
 * default control endpoint 0 and an interrupt-in endpoint (any other endpoint
 * number).
 */
#define USB_CFG_HAVE_INTRIN_ENDPOINT3   0
/* Define this to 1 if you want to compile a version with three endpoints: The
 * default control endpoint 0, an interrupt-in endpoint 3 (or the number
 * configured below) and a catch-all default interrupt-in endpoint as above.
 * You must also define USB_CFG_HAVE_INTRIN_ENDPOINT to 1 for this feature.
 */
#define USB_CFG_EP3_NUMBER              3
/* If the so-called endpoint 3 is used, it can now be configured to any other
 * endpoint number (except 0) with this macro. Default if undefined is 3.
 */
/* #define USB_INITIAL_DATATOKEN           USBPID_DATA1 */
/* The above macro defines the startup condition for data toggling on the
 * interrupt/bulk endpoints 1 and 3. Defaults to USBPID_DATA1.
 * Since the token is toggled BEFORE sending any data, the first packet is
 * sent with the oposite value of this configuration!
 */
#define USB_CFG_IMPLEMENT_HALT          0
/* Define this to 1 if you also want to implement the ENDPOINT_HALT feature
 * for endpoint 1 (interrupt endpoint). Although you may not need this feature,
 * it is required by the standard. We have made it a config option because it
 * bloats the code considerably.
 */
#define USB_CFG_SUPPRESS_INTR_CODE      0
/* Define this to 1 if you want to declare interrupt-in endpoints, but don't
 * want to send any data over them. If this macro is defined to 1, functions
 * usbSetInterrupt() and usbSetInterrupt3() are omitted. This is useful if
 * you need the interrupt-in endpoints in order to comply to an interface
 * (e.g. HID), but never want to send any data. This option saves a couple
 * of bytes in flash memory and the transmit buffers in RAM.
 */
#define USB_CFG_INTR_POLL_INTERVAL      10
/* If you compile a version with endpoint 1 (interrupt-in), this is the poll
 * interval. The value is in milliseconds and must not be less than 10 ms for
 * low speed devices.
 */
#ifndef USB_CFG_IS_SELF_POWERED // allow bootloaderconfig.h to override
#define USB_CFG_IS_SELF_POWERED         0
#endif
/* Define this to 1 if the device has its own power supply. Set it to 0 if the
 * device is powered from the USB bus.
 */
#ifndef USB_CFG_MAX_BUS_POWER   // allow bootloaderconfig.h to override
#define USB_CFG_MAX_BUS_POWER           100
#endif
/* Set this variable to the maximum USB bus power consumption of your device.
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

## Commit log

2014-05-19 fix drill circles
2014-05-20 fix some traces
    [picoavr.brd]
2014-05-28 change directory structure
    [picoavr.brd, picoavr.sch]
2014-06-02 add missing labels
    [picoavr.sch]
2014-06-05 changed button placement
    [picoavr.brd]
2014-06-05 change led placement
    [picoavr.brd]
2014-06-05 new hardware revision
    [picoavr.brd, picoavr.sch]
2014-06-05 moved labels
    [picoavr.brd]
2014-06-05 fix pin spacing
    [picoavr.brd]
2014-06-05 tweaked dimensions
    [picoavr.brd, picoavr.sch]
2014-06-11 change pc7/pc6 label to adc7/adc6
    [picoavr.brd]
2014-06-23 minor trace tweaks
    [picoavr.brd]
2014-06-25 add optional reset button
    [picoavr.brd, picoavr.sch]
2014-06-25 move reset for silk screen
    [picoavr.brd]
2014-07-10 update device in bootloader

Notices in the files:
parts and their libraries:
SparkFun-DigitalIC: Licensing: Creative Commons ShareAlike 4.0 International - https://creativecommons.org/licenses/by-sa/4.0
